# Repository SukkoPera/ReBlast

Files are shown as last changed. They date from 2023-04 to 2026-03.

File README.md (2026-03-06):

# ReBlast





ReBlast is an 8-bit Digital-to-Analog + Analog-to-Digital converter add-on for Commodore 16, 116 and Plus/4 SIDcards.

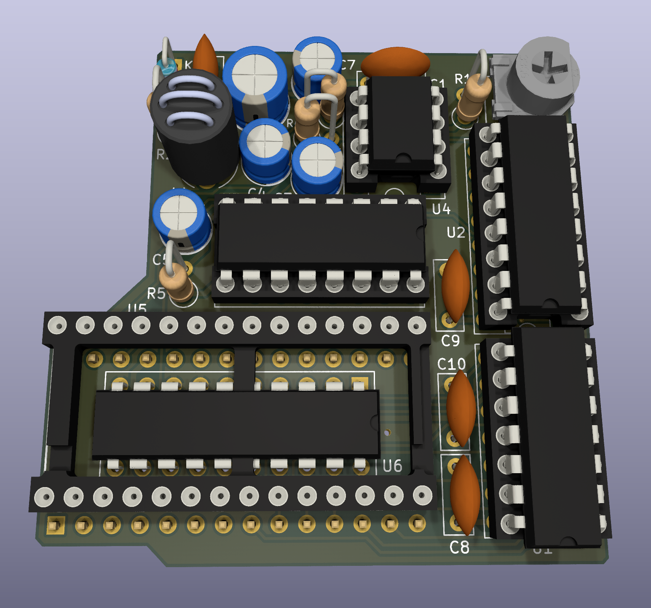
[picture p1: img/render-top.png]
Board


## Summary
ReBlast is basically a replica of [Solder of Synergy's Digi-Blaster](https://plus4world.powweb.com/hardware/Digi-Blaster). It uses the [ZN428](doc/zn428.pdf) DAC originally made by Ferranti and the [ADC0804](doc/adc0804.pdf) ADC by Signetics. Both these chips are old-fashioned and out of production, but they can still be found relatively easily and cheaply.

ReBlast was sized and shaped so that it fits perfectly on a [ReSeed](https://github.com/SukkoPera/ReSeed) card.

The DAC feeds its output into the SID's EXT_IN pin, which means that you will hear it mixed with the computer audio or on the output jack of the ReSeed card. Similarly, the ADC takes its input from the ReSeed input jack.

The DAC part of ReBlast is compatible with [ReVox](https://github.com/SukkoPera/ReVox), but ReBlast can also take advantage of the SID to apply filters to the audio signal.

APOS's [Digital Composing Kit 2.0](https://plus4world.powweb.com/software/Digital_Composing_Kit_V2_0) or [the older version](https://plus4world.powweb.com/software/Digital_Composing_Kit) can be used to sample, compose and edit samples.

## Installation
### ReSeed
Installation is very easy, in particular if your ReSeed card was build with the DC-DC step-up converter and no regulator at U6:
- Remove the SID chip from your board.
- Plug ReBlast where the SID chip was.
- Plug the SID into the socket on the ReBlast board.

If your ReSeed was built with the TL497 and/or with a linear regulator at U6, you will probably need to use a few chip sockets as "spacers" in order for the board to rise enough over the other components. If you really want to use a linear regulator, it is probably best to use an L78L09/L78L12 since they are much less tall than the LM7809/LM7812.

When plugging ReSeed into your computer, it might feel like ReBlast is preventing it from being completely inserted, but the card should actually slide in enough to work correctly.

### LittleSixteen
ReBlast has not yet been tested on a LittleSixteen board, but there is no reason why it should not work, except for physical fitting issues. Probably the usage of additional spacer sockets is necessary, as well as using smaller voltage regulators.

## Testing
I suggest to use [WavePlay-SD](https://plus4world.powweb.com/software/WavePlay-SD), a great piece of software that plays music with superb quality. Enter the Setup menu with <kbd>CTRL+S</kbd> and select *INT. INTL DGB:0* using the *MOD* button.

More software for the card can be found [here](https://plus4world.powweb.com/effects/Digi-Blaster_Support).

## Programming
### DAC
The DAC is exposed at address $FD5E or $FE9E.

ReVox has no buffer, which means it must be fed audio samples in real-time. This is not a trivial task and existing software should be analyzed in order to learn the best techniques to do so.

Keep in mind that since the DAC feeds its output into the SID's EXT_IN pin, so the volume for that must be set through $FD58. This also opens interesting possibilities since the SID can apply filters to the audio coming in through that pin. See [Second Mod](https://plus4world.powweb.com/software/Second_Mod) for an example of that.

Detailed information, including code, can be found on the [ReVox Wiki](https://github.com/SukkoPera/ReVox/wiki).

### ADC
The ADC is exposed at $FD5F or $FE9F (64863 decimal). First of all, it needs calibration. This can easily be done with the following BASIC line:

    DO : POKE 64863,0 : PRINT PEEK(64863) : LOOP

Then use a screwdriver to turn the pot on the board until the displayed value is mostly stable around 128.

Writing any value to the register starts the sampling process. Then at least 48 clock cycles must elapse before the sampled value can be read from the same register. Since the conversion is directly linked to the clock of the Plus/4, this means that the smallest timer value for timer 1 is 48.

## Releases
If you want to get this board produced, you are recommended to get [the latest release](https://github.com/SukkoPera/ReBlast/releases) rather than the current git version, as the latter might be under development and is not guaranteed to be working.

Every release is accompanied by its Bill Of Materials (BOM) file and any relevant notes about it, which you are recommended to read carefully.

## License
The ReBlast documentation, including the design itself, is copyright &copy; SukkoPera 2024 and is licensed under the [Creative Commons Attribution-NonCommercial-ShareAlike 4.0 International License](https://creativecommons.org/licenses/by-nc-sa/4.0/).

This documentation is distributed *as is* and WITHOUT ANY EXPRESS OR IMPLIED WARRANTIES whatsoever with respect to its functionality, operability or use, including, without limitation, any implied warranties OF MERCHANTABILITY, SATISFACTORY QUALITY, FITNESS FOR A PARTICULAR PURPOSE or infringement. We expressly disclaim any liability whatsoever for any direct, indirect, consequential, incidental or special damages, including, without limitation, lost revenues, lost profits, losses resulting from business interruption or loss of data, regardless of the form of action or legal theory under which the liability may be asserted, even if advised of the possibility or likelihood of such damages.

## Support the Project
If you want to get some boards manufactured, you can get them from PCBWay through this link:

PCB from PCBWay (https://www.pcbway.com/project/shareproject/ReBlast_8_Bit_DAC_ADC_Add_On_for_Commodore_16_Plus4_SIDcards_3124785d.html)

You get my gratitude and cheap, professionally-made and good quality PCBs, I get some credit that will help with this and [other projects](https://www.pcbway.com/project/member/shareproject/?bmbid=41100). You won't even have to worry about the various PCB options, it's all pre-configured for you!

Also, if you still have to register, [you can use this link](https://www.pcbway.com/setinvite.aspx?inviteid=41100) to get some bonus initial credit (and yield me some more).

You can also buy me a coffee if you want:



## Thanks
- Solder, for designing the original card and sharing its schematics.
- Haegar and TLC, for help with the design.
- Lettercorner Studio for the [Sterion Font](https://www.fontspace.com/sterion-font-f113971) used in the logo.

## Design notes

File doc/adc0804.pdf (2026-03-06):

This Material Copyrighted By Its Respective Manufacturer

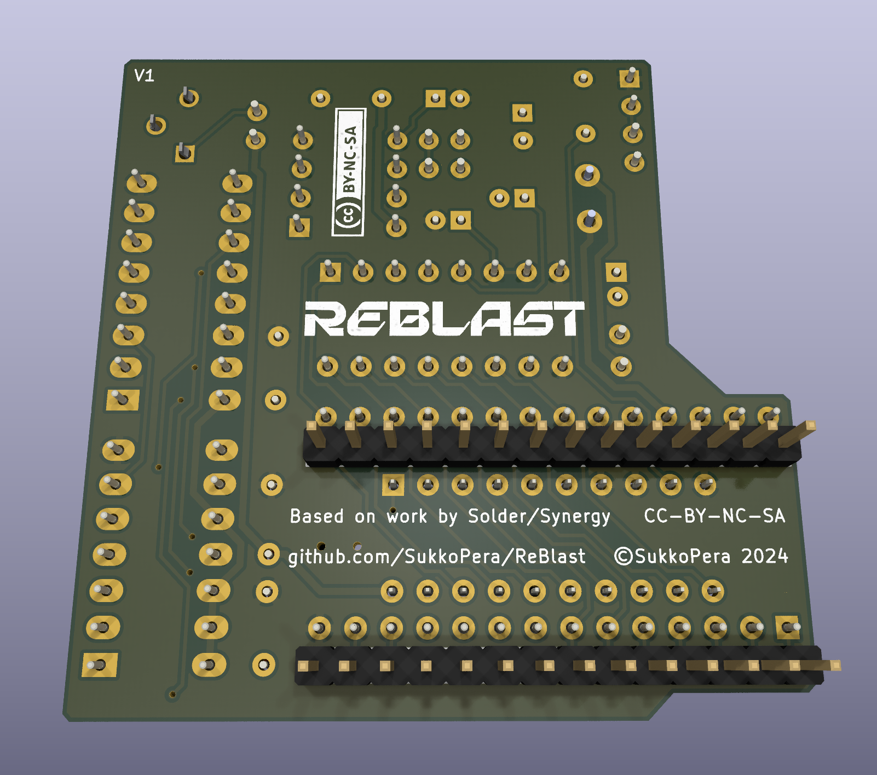
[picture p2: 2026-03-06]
img/render-bottom.png

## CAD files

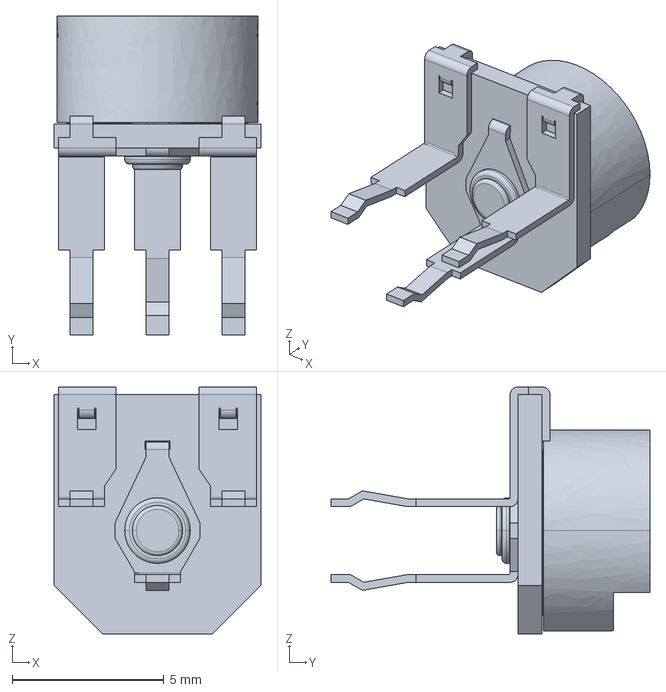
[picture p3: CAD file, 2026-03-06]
3dModels/3306p-1-101.stp
6.81 x 10.5 x 8.13 mm

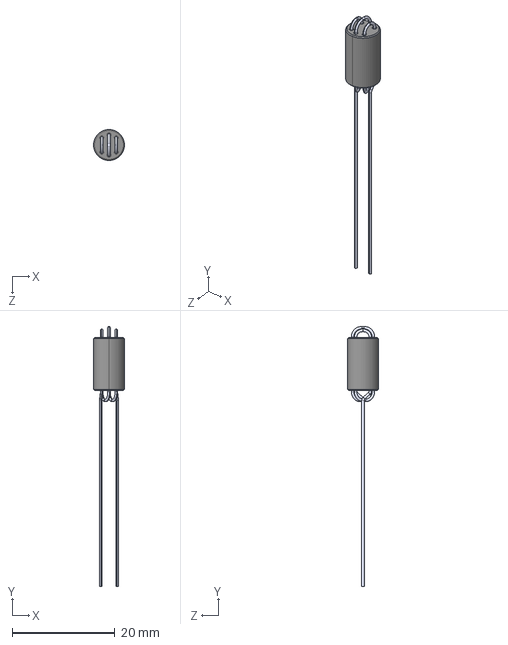
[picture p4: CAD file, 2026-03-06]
3dModels/28C0236-0EW-10--3DModel-STEP-460648.STEP
6.00 x 50.5 x 6.00 mm

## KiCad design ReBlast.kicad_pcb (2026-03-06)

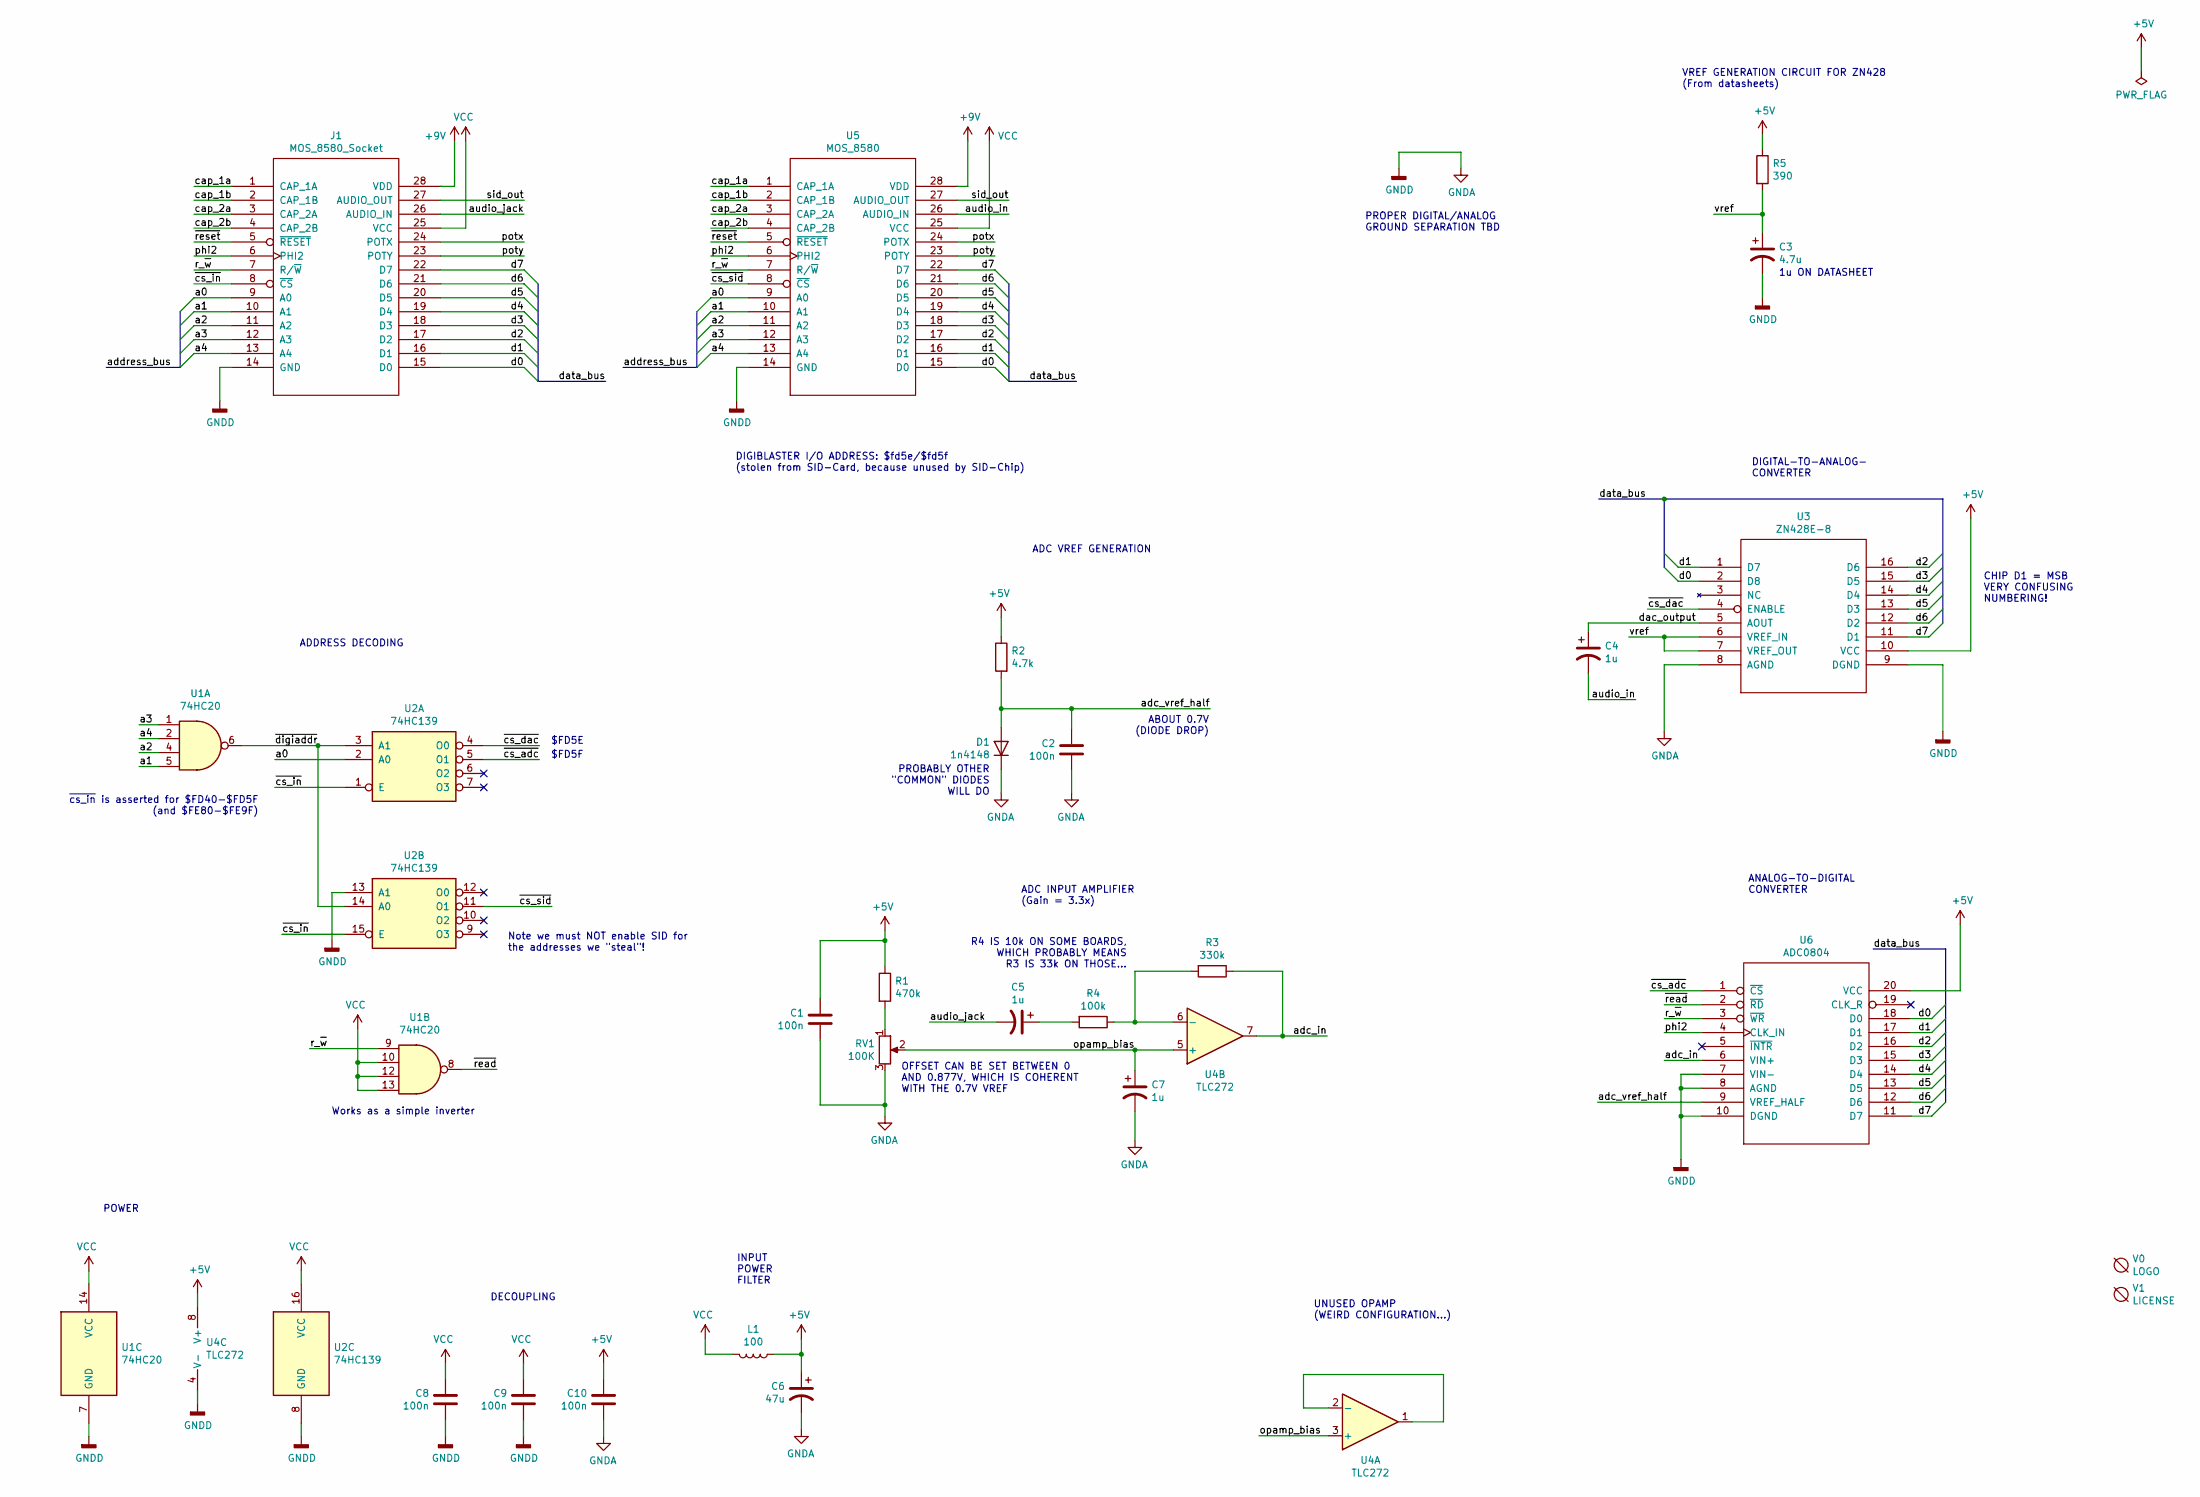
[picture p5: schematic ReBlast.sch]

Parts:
C1, C2, C8, C9, C10: 100n; C_Disc_D7.0mm_W2.5mm_P5.00mm
C3: 4.7u; CP_Radial_D5.0mm_P2.00mm
C4, C5, C7: 1u; CP_Radial_D5.0mm_P2.00mm
C6: 47u; CP_Radial_D6.3mm_P2.50mm
D1: 1n4148; D_DO-35_SOD27_P2.54mm_Vertical_KathodeUp
J1: MOS_8580_Socket; DIP-28_W15.24mm_Socket
L1: 100; L_Radial_D6.0mm_P4.00mm
R1: 470k; R_Axial_DIN0207_L6.3mm_D2.5mm_P2.54mm_Vertical
R2: 4.7k; R_Axial_DIN0207_L6.3mm_D2.5mm_P2.54mm_Vertical
R3: 330k; R_Axial_DIN0207_L6.3mm_D2.5mm_P2.54mm_Vertical
R4: 100k; R_Axial_DIN0207_L6.3mm_D2.5mm_P2.54mm_Vertical
R5: 390; R_Axial_DIN0207_L6.3mm_D2.5mm_P2.54mm_Vertical
RV1: 100K; Pot_Bourns_3306P
U1: 74HC20; DIP-14_W7.62mm_Socket_LongPads
U2: 74HC139; DIP-16_W7.62mm_Socket_LongPads
U3: ZN428E-8; DIP-16_W7.62mm_Socket
U4: TLC272; DIP-8_W7.62mm_Socket
U5: MOS_8580; DIP-28_W15.24mm_Socket
U6: ADC0804; DIP-20_W7.62mm_Socket
V0: LOGO; logo
V1: LICENSE; cc_by_nc_sa_small

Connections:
+5V: C1.1, C6.1, C10.1, L1.2, R1.1, R2.1, R5.1, U3.10 (VCC), U4.8 (V+), U6.20 (VCC)
+9V: J1.28 (VDD), U5.28 (VDD)
/a0: J1.9 (A0), U2.2 (A0), U5.9 (A0)
/a1: J1.10 (A1), U1.5, U5.10 (A1)
/a2: J1.11 (A2), U1.4, U5.11 (A2)
/a3: J1.12 (A3), U1.1, U5.12 (A3)
/a4: J1.13 (A4), U1.2, U5.13 (A4)
/adc_in: R3.1, U4.7, U6.6 (VIN+)
/adc_vref_half: C2.1, D1.2 (A), R2.2, U6.9 (VREF_HALF)
/audio_in: C4.2, U5.26 (AUDIO_IN)
/audio_jack: C5.2, J1.26 (AUDIO_IN)
/cap_1a: J1.1 (CAP_1A), U5.1 (CAP_1A)
/cap_1b: J1.2 (CAP_1B), U5.2 (CAP_1B)
/cap_2a: J1.3 (CAP_2A), U5.3 (CAP_2A)
/cap_2b: J1.4 (CAP_2B), U5.4 (CAP_2B)
/d0: J1.15 (D0), U3.2 (D8), U5.15 (D0), U6.18 (D0)
/d1: J1.16 (D1), U3.1 (D7), U5.16 (D1), U6.17 (D1)
/d2: J1.17 (D2), U3.16 (D6), U5.17 (D2), U6.16 (D2)
/d3: J1.18 (D3), U3.15 (D5), U5.18 (D3), U6.15 (D3)
/d4: J1.19 (D4), U3.14 (D4), U5.19 (D4), U6.14 (D4)
/d5: J1.20 (D5), U3.13 (D3), U5.20 (D5), U6.13 (D5)
/d6: J1.21 (D6), U3.12 (D2), U5.21 (D6), U6.12 (D6)
/d7: J1.22 (D7), U3.11 (D1), U5.22 (D7), U6.11 (D7)
/dac_output: C4.1, U3.5 (AOUT)
/opamp_bias: C7.1, RV1.2, U4.3 (+), U4.5 (+)
/phi2: J1.6 (PHI2), U5.6 (PHI2), U6.4 (CLK_IN)
/potx: J1.24 (POTX), U5.24 (POTX)
/poty: J1.23 (POTY), U5.23 (POTY)
/r_~w: J1.7 (R/~W), U1.9, U5.7 (R/~W), U6.3 (~WR)
/sid_out: J1.27 (AUDIO_OUT), U5.27 (AUDIO_OUT)
/vref: C3.1, R5.2, U3.6 (VREF_IN), U3.7 (VREF_OUT)
/~cs_adc: U2.5 (O1), U6.1 (~CS)
/~cs_dac: U2.4 (O0), U3.4 (ENABLE)
/~cs_in: J1.8 (~CS), U2.1 (E), U2.15 (E)
/~cs_sid: U2.11 (O1), U5.8 (~CS)
/~digiaddr: U1.6, U2.3 (A1), U2.14 (A0)
/~read: U1.8, U6.2 (~RD)
/~reset: J1.5 (~RESET), U5.5 (~RESET)
GNDA: C1.2, C2.2, C3.2, C6.2, C7.2, C8.2, C9.2, C10.2, D1.1 (K), J1.14 (GND), RV1.3, U1.7 (GND), U2.8 (GND), U2.13 (A1), U3.8 (AGND), U3.9 (DGND), U4.4 (V-), U5.14 (GND), U6.7 (VIN-), U6.8 (AGND), U6.10 (DGND)
unnamed: C5.1, R4.2
unnamed: R1.2, RV1.1
unnamed: R3.2, R4.1, U4.6 (-)
unnamed: U4.1, U4.2 (-)
VCC: C8.1, C9.1, J1.25 (VCC), L1.1, U1.10, U1.12, U1.13, U1.14 (VCC), U2.16 (VCC), U5.25 (VCC)

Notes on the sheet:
DIGIBLASTER I/O ADDRESS: $fd5e/$fd5f (stolen from SID-Card, because unused by SID-Chip)
$FD5E
$FD5F
VREF GENERATION CIRCUIT FOR ZN428 (From datasheets)
ANALOG-TO-DIGITAL CONVERTER
DIGITAL-TO-ANALOG- CONVERTER
ADDRESS DECODING
Note we must NOT enable SID for the addresses we "steal"!
CHIP D1 = MSB VERY CONFUSING NUMBERING!
INPUT POWER FILTER
1u ON DATASHEET
PROPER DIGITAL/ANALOG GROUND SEPARATION TBD
R4 IS 10k ON SOME BOARDS, WHICH PROBABLY MEANS R3 IS 33k ON THOSE...
PROBABLY OTHER "COMMON" DIODES WILL DO
UNUSED OPAMP (WEIRD CONFIGURATION...)
~cs_in~ is asserted for $FD40-$FD5F (and $FE80-$FE9F)
Works as a simple inverter
ADC INPUT AMPLIFIER (Gain = 3.3x)
ADC VREF GENERATION
OFFSET CAN BE SET BETWEEN 0 AND 0.877V, WHICH IS COHERENT WITH THE 0.7V VREF
ABOUT 0.7V (DIODE DROP)
DECOUPLING
POWER

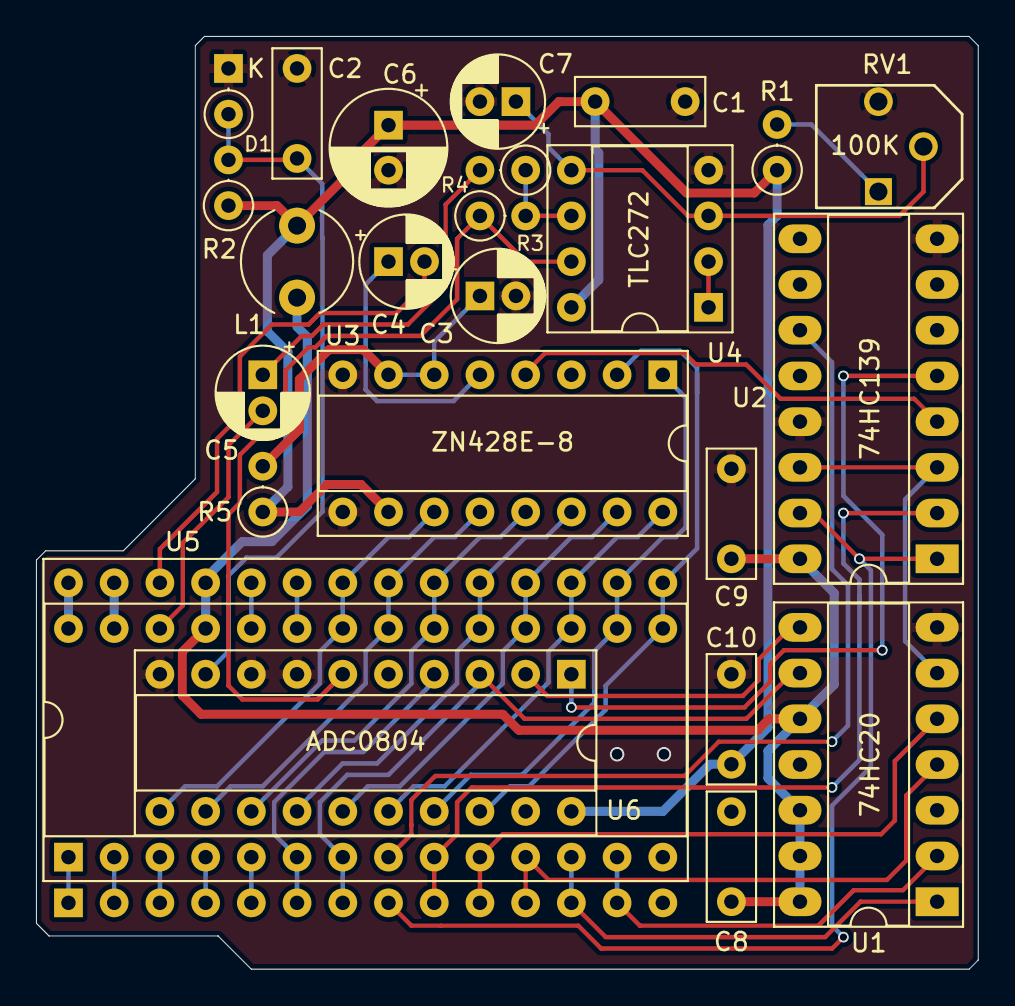
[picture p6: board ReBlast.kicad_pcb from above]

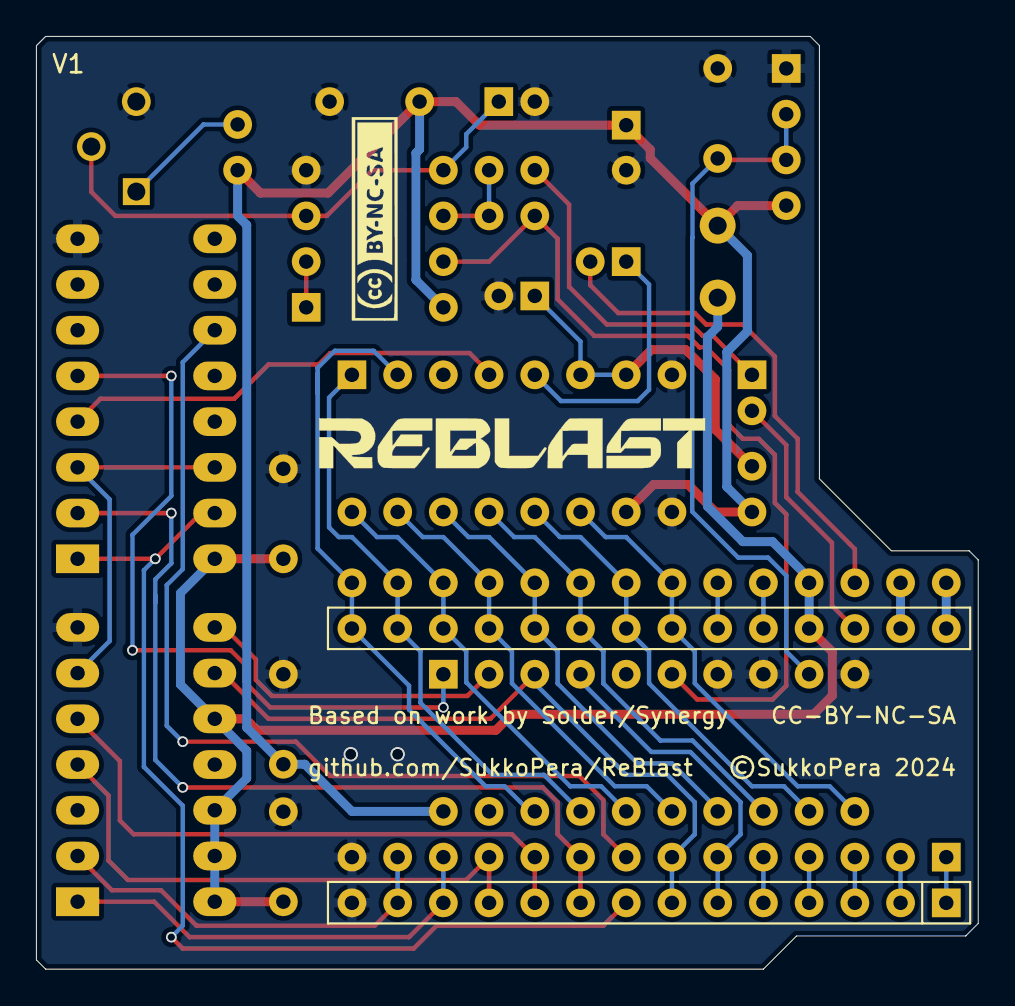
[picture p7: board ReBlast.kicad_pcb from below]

Board: 2 copper layers, 52.3 x 51.8 mm, 27 parts (2 on the bottom side), 44 nets.

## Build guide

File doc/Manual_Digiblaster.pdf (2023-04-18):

Anleitung zum Digiblaster

1. Hardware

Legen Sie die SID-Card mit der Anschlussleiste nach vorn vor sich hin. Die Kerbe des SID zeigt nun nach links. Hebeln Sie mit einem kleinen Schraubenzieher vorsichtig den SID aus dem Sockel. Stecken Sie dann den Digiblaster anstelle des SID so in die Fassung, dass der längere Teil des Digiblasters nach hinten zeigt.
Nun stecken Sie den SID in den Digiblaster. Dabei muss die Kerbe am Gehäuse, wie vorher auch, links sein. Das war schon alles. Für falsch installierte Digiblaster bzw. verkehrt herum eingesetzte SIDs kann ich keine Haftung übernehmen. Klar, dass für diese Arbeiten der Computer ausgeschaltet ist, bzw. die SID-Card nicht im Computer steckt.
2. Abgleich des Samplers

Wenn Sie den Digitizer auf dem Digiblaster verwenden wollen, muss dieser zuerst abgeglichen werden. Das erfolgt am einfachsten mit folgender Zeile:

do:pO64863,0:?pE(64863):loop

Drehen Sie nun den Regler am Digiblaster so, dass der angezeigte Wert um die Zahl 128 schwankt.

3. Anschluss

Wollen Sie nur mit dem Digiblaster Musik hören, so sind keine weiteren Anschlüsse nötig. Die Ausgabe erfolgt über den SID und die SID-Card. Möchten Sie Musik digitalisieren, so schließen Sie das beigelegte Kabel an den "Audio In"-Eingang der SID-Card und an den Kopfhörerausgang eines Walkmans, Recorders oder der Stereo-Anlage an. Stellen Sie die Lautstärke zunächst auf Null. Verwenden Sie nur das beigelegte Kabel, da es gefahrlos beide Kanäle zusammenschaltet. Ein Verlängerungskabel kann jedoch zusätzlich benutzt werden.

4. Software

Zum Sampeln, Komponieren und Bearbeiten von Digis können Sie das beigelegte "Digital Composing Kit" von APOS verwenden. Eine Anleitung dieses Programms finden Sie auf der Main-Disk, außerdem zu jedem Programmteil zwei Hilfsbildschirme. Starten Sie das Programm unter OS92 mit la"* oder sonst mit load"*",8,1. Sie können aber jeden einzelnen Programmteil auch mit DLOAD laden.

5. Für Profis und Programmierer

Von dem Digiblaster werden folgende Adressen verwendet, die aus dem Adressbereich des SID stammen:

$fd5e, 64862 ist das Ausgaberegister an den Digital/Analogwandler.
$fd5f, 64863 ist das Register für den Analog-Digitalwandler.

Das Schreiben eines beliebigen Wertes startet den Sample-Vorgang. Dann müssen mindestens 48 Takzyklen vergehen, bevor der gesampelte Wert aus diesem Register ausgelesen werden kann. Da die Umsetzung direkt mit dem Takt des Plus/4 verbunden ist, bedeutet dies, dass der kleinste Timerwert für Timer 1 also 48 ist.
Der Digital/Analogwandler führt sein Ausgangssignal zum SID-Audio-Eingang. Es ist deshalb wichtig, dass im SID die Lautstärke gesetzt wird, damit man etwas hört. Außerdem sind noch weitere Beeinflussungsmöglichkeiten durch die Filter des SID möglich. Genaues können Sie der Übersicht zu den SID-Registern entnehmen, die Sie mit der SID-Card bekamen.
6. Copyrights

Auf den Digiblaster habe ich das Copyright. Der Digiblaster ist eine Entwicklung von mir. Auf das Digital-Composing-Kit hat APOS das Copyright. Das Programm ist keine PD oder Freeware. Es darf also nicht ohne Zustimmung weiterkopiert werden. Das Programm ist bei APOS für 10DM auch extra erhältlich. Die Software ist Freeware.

(C) 4/1994, 2006 Solder/Synergy, Christian Schäffner, Gänsekamp 21, 38162 Schandelah, solder@gmx.net
APOS, Christian Prieth, Hermannstraße 6, 31195 Lamspringe.

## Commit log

2026-03-06 Suppositions in progress...
    [ReBlast.kicad_pcb, ReBlast.sch]
2026-03-06 Back side is 99% done. Top side is full of doubts...
    [ReBlast.kicad_pcb, ReBlast.sch]
2026-03-06 Power circuit almost makes sense
    [ReBlast.kicad_pcb, ReBlast.sch]
2026-03-06 Nothing makes sense
    [ReBlast.kicad_pcb, ReBlast.sch]
2026-03-06 Try to come up with some values for caps
    [ReBlast.kicad_pcb, ReBlast.sch]
2026-03-06 Fix socket
    [ReBlast.kicad_pcb, ReBlast.sch]
2026-03-06 Fix DRC
    [ReBlast.kicad_pcb, ReBlast.sch]
2026-03-06 Add some notes, fix ERC, adjust some tracks
    [ReBlast.kicad_pcb, ReBlast.sch]
2026-03-06 AT LAAAAAAAAAST! Though I must admit that R6 is really misleading...
    [ReBlast.kicad_pcb, ReBlast.sch]
2026-03-06 Almost there...
    [28C0236-0EW-10--3DModel-STEP-460648.STEP, 3306p-1-101.stp, B103 - 10K Potansiyometre - 22.11.2021.STEP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]
2026-03-06 Better ground plane
    [ReBlast.kicad_pcb]
2026-03-06 Center U6 within U5
    [ReBlast.kicad_pcb]
2026-03-06 Swap SID socket and connector This is so that the board sits a bit further up the ReBlast card and doesn't hit the computer case
    [ReBlast.kicad_pcb]
2026-03-06 Add logo, etc.
    [ReBlast.kicad_pcb, ReBlast.sch]

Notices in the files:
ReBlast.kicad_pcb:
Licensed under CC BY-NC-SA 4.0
